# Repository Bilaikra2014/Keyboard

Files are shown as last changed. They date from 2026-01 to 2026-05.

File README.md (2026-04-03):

# ⌨️ WirelessKeyboard Project

Ce projet a pour objectif la conception et la fabrication d'un clavier mécanique (Filaire USB-C / Sans-fil). Le système repose sur un écosystème ESP32 permettant une communication rapide et personnalisée. Ce projet est une première version de test, une autre version pourrait être conçue dans le but de rechercher encore plus de perfomance en utilisant des composants plus adaptés.

## 📋 Présentation du projet

Le projet consiste à créer deux dispositifs distincts :
1.  **Le Clavier (Émetteur) :** Gère la matrice de touches, la batterie et la communication.
2.  **Le Récepteur (Dongle) :** Reçoit les données sans fil et les transmet à l'ordinateur via USB.

L'architecture se divise en trois axes de développement :
* **Électronique :** Conception des schémas et des PCB.
* **Informatique :** Développement des firmwares d'émission et de réception.
* **Mécanique :** Conception CAO 3D du boîtier du clavier et de celui dongle.

---

## 🛠️ Spécifications Matérielles

### 1. Le Clavier (ESP32-S3)
Le choix de l'**ESP32-S3** est motivé par son support **USB natif**, indispensable pour le mode filaire.
* **Prise USB C** pour le mode filaire.
* **Alimentation :** Batterie LiPo 1S (3.7V).
* **Régulation :** Passage du 5V(USB)/3v7(Batterie) vers 3.3V via un régulateur de tension (LDO).
* **Gestion de charge :** Circuit de charge intégré permettant :
    * L'alimentation du µC via USB lors du branchement.
    * La recharge simultanée de la batterie.
    * Le basculement automatique sur batterie lors du débranchement.

### 2. Le Récepteur (ESP32-S3-MINI)

      

L'**ESP32-S3-MINI** est utilisé pour son format compact et son coût réduit. Il fait office de pont entre le clavier et le PC.
* **Prise USB A** pour le brancher à l'ordinateur.
* **Interface :** Prise USB-A mâle.
* **Alimentation :** LDO convertissant le 5V USB en 3.3V.
* **Contrôles physiques :**
    * **Bouton BOOT :** Maintien du GPIO 9 à la masse pour le mode téléchargement.
    * **Bouton RESET :** Redémarrage du contrôleur pour les phases de test.
* **Câblage USB natif :**
    * `D+` ↔ GPIO 19
    * `D-` ↔ GPIO 18
    * `V+` ↔ Entrée LDO
    * `GND` ↔ Masse commune

---

## 📂 Structure du projet

Chaque sous-structure du projet aura son propre fichier Readme dédiée à la partie qu'elle traite.

```text
.
├── 📁 Electronique        # Schémas et PCB (KiCad)
│   ├── 📁 Lib              # Librairie Kicad
│   ├── 📁 Clavier          # Code de l'émetteur
│   └── 📁 Recepteur        # Code du récepteur
├── 📁 Informatique        # Code source ESP32
│   ├── 📁 Clavier          # Code de l'émetteur
│   └── 📁 Recepteur        # Code du récepteur
├── 📁 Mecanique          # Modèles 3D (STL/STEP)
└── README.md                #README global du projet

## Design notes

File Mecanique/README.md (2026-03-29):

La partie mécanique se divise en 3 principales étapes : 
- La plaque de maintient (Switch Plate) qui permettra d'aligner parfaitement les switchs lors de la soudure.
- Les touches de clavier (KeyCaps) pour appuyer sur les switchs
- Le boitier du clavier.

plaque : https://www.keyboard-layout-editor.com/#/gists/d94be4b51da24dfe0b23f572a5654290
touches : https://srwi.github.io/keycap_generator/

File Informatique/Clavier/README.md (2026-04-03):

# Partie informatique - Clavier

## Fonctions à réaliser

- Lire les touches de la matrice
- Lire l'encodeurs
- Détecter le mode d'alimentation : 
  - Alimentation sur batterie : Clavier en mode sans-fil donc les touches sont envoyées par ESP-NOW
  - Alimentation par USB : Clavier en mode filaire
- Mesurer la charge de la batterie et gérer l'activation de la charge.

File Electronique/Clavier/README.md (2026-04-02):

# Partie Electronique - Clavier

Dans cette partie, le clavier se sépare en deux sous-ensembles : la matrice de touche ainsi que la carte avec l'ESP32. Ces deux touches seront reliées de manière filaire. 
Séparer ces 2 sous-ensembles a permit un routage plus simple niveau PCB.

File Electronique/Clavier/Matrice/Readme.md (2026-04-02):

 # Partie electronique - Matrice de touche et encodeur
 
## Matrice de touche

Le clavier comporte 71 touches. Avec un système de surveillance normal des touches, il faudrait 71 GPIOs ce qui est beaucoup trop. Un système de matrice à donc été utilisé, permettant ainsi de réduire le nombre de broches utilisées. La matrice de touche se compose de 5 lignes et 15 colonnes, ce qui fait que l'on utiliser que 20 GPIOs. 

**Fonctionnement de la matrice** : 
- Le µC met successivement chaque ligne à l'état BAS.
- Il lit ensuite l'état des colonnes maintenues à l'état HAUT par des résistances de pull-up.
- Si une colonne est detectée à l'état BAS, c'est que la touche correspondant au croisement est activée.

**Le problème du Ghosting** : 

Sur une matrice simple, presser trois touches simultanément (ex: A, Q et S) peut créer un chemin de retour parasite. Le courant "remonte" par une ligne adjacente, faisant croire au contrôleur qu'une quatrième touche fantôme (Ghost) est pressée.
Pour pallier ce problème, chaque interrupteur est couplé à une diode de signal 1N4148 : 
- Rôle : Elle force le courant à circuler dans un seul sens (Ligne → Colonne).
- Résultat : Cela permet le N-Key Rollover (NKRO), garantissant que chaque pression de touche est enregistrée indépendamment, quel que soit le nombre de touches pressées simultanément.

Les touches utilisées sont des switchs mécanique **Cherry MX Red** commandés sur AliExpress.



## Gestion de l'encodeur

L'encodeur permet la gestion du volume.

L'encodeur utilisé (déjà présent à l'école) possède une fonction RGB avec les 3 diodes (pin 1,2 et 4) mais ne seront pas utilisée ici.



## Résultat final

Voici la vue 3D du Résultat final via logiciel : 



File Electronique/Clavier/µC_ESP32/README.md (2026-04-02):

 # Partie electronique - Microcontrôleur
## Gestion d'alimentation et Chargeur Li-Po

Lorsque la batterie est déchargée, le clavier sera branché à l'ordinateur via une prise USB. La prise de l'ordinateur va alimenter le clavier, et charger la batterie avec le courant restant. Une prise USB A d'ordinateur peut fournir en général jusqu'à 500 mA. 

Pour gérer l'alimentation et la charge, le composant utilisé sera le [MCP73871](https://ww1.microchip.com/downloads/en/DeviceDoc/MCP73871-Data-Sheet-20002090E.pdf) qui permet : 
  - **Gestion du Power Path** : Alimente le système depuis l'USB tout en gérant la charge la batterie
  - **Partage du courant** : Donne la priorité à l'alimentation du système, le courant restant est alloué à la charge de la batterie



**Alimentation et Puissance**
  - In (18) : Alimentation du composant -> USB
  - Out (20) : Alimentation du système -> Régulateur LDO
  - Vbat (14) : Charge de la batterie -> Vbat
  - Vss (10) : Masse -> GND

**Contrôle et Logique**:
  - SEL (3) : Limite de courant à tirer sur l'USB -> LOW pour 500 mA (HIGH pour 1,8)
  - PROG2 (4) : Courant d'entré max à tirer -> HIGH pour 500 mA (HIGH pour 100mA)  
  - CE (17) : Activation du système à l'état haut -> Vusb
  - TE (9) : Sécurité interne du temps de charge -> GND

**Programmation et Sécurité**:
  - PROG1 (13) : Courant de charge rapide -> R = 1000V/Ireg, on veut Ireg = 250mA donc R = 4k
  - PROG3 (12) : Seuil de fin de charge -> R = 40k
  - VPCC (2)   : 
  - VBAT_S (16): Sonde de tension -> Vbat
  - THERM (5)  : Capteur de temperature ->  

**Indicateurs visuel**: Ces broches tirent vers la masse, on y connecte des leds
  - PG (6)    : Indication que l'USB est branché, à brancher à l'ESP32 pour qu'il detecte si on est sur batterie ou USB
  - STAT1 (8) : Indication de la phase de charge 
  - STAT2 (7) : Indication de la fin de charge 

## Régulateur de tension

Le µC sera alimenté par du 5v ou bien du 3v7, or il n'accepte que du 3v3. Il faut donc utiliser un régulateur de tension. Le régulateur de tension utilisé est un [BU33SD5WGTR](https://www.rohm.com/products/power-management/linear-regulators/single-output-ldo-regulators/bu33sd5wg-product).



## Mesure de la batterie

La mesure de la batterie permet d'indiquer à l'utilisateur si le clavier à besoin d'être chargé ou pas. La tension étant supérieur aux 3v3 de l'esp32, il faut diviser cette tension pour qu'elle puisse être lue par l'esp32 à travers un pont diviseur de tension.



**Pont Diviseur de tension**:

Le pont diviseur de tension formé par R16 et R17 permet d'ajuster la tension mesurée par L'ESP32. La tension de la batterie varie entre 4v2 et 3v7, ce qui donnera pour l'ESP32 une tension mesurée entre 3v et 2,64v, ce qui est dans la plage de donnée mesurable.

**Ajout des transistors Q3 et Q4**:

Utiliser simplement un pont diviseur consommerait du courant en permanance, aussi minime soit-il. C'est pour cela que des transistors ont été ajouté. Le transistor Q2 est un mosfet canal P, qui lie la batterie au pont diviseur lorsqu'il est passant. Ce transistor est piloté par son complémentaire Q1, un canal N commandé par l'esp32. Ce transistor sera passant uniquement lors de la mesure déclenchée par l'ESP32. La résistance R15 sert de pull-up pour maintenir le transistor Q2 bloqué quand Q1 est bloqué. Ce montage permet de relier le pont diviseur à la batterie uniquement lors de la mesure, limitant ainsi la consommation du pont diviseur.

## USB-C et protection ESD

Le port USB-C permet l'utilisation filaire du clavier, ainsi que la recharge de la batterie.



Les broches D+ et D- permettent la communication ESP32-Ordinateur. 
Les broches CC1 et CC2 doivent être liées à des résistances de 5k1 de pull-down pour que la source détecte la présence du clavier et délivre ainsi le 5v.

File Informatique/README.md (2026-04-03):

## 📡 Protocoles de Communication

### Communication Sans-fil ([ESP-NOW](https://wiki-fablab.grandbesancon.fr/doku.php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,de%20donn%C3%A9es%20directement%20et%20simplement.))
Pour minimiser la latence, le projet utilise **ESP-NOW**, un protocole de connexion sans fil à basse consommation d'Espressif annoncé avec une latence < 10ms.

### Communication PC
Le récepteur utilise les bibliothèques `USB.h` et `USBHIDKeyboard.h` pour simuler un clavier standard auprès du système d'exploitation.

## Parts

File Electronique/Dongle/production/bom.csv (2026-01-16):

Designator | Footprint | Quantity | Value | LCSC Part #
C1, C2 | 0603 | 2 | 1µ
D4, D5 | 0603 | 2 | LED
J1 | USB_A_CNCTech_1001-011-01101_Horizontal | 1 | USB_A
R2, R3 | 0805 | 2 | 470
R4, R5 | 0805 | 2 | 10k
SW3, SW4 | SW_Tactile_SPST_NO_Straight_CK_PTS636Sx25SMTRLFS | 2 | SW_Push
U3 | ESP32-S2-MINI-1 | 1 | ESP32-S3-MINI-1
U4 | SOT-23-5 | 1 | TLV75533PDBV

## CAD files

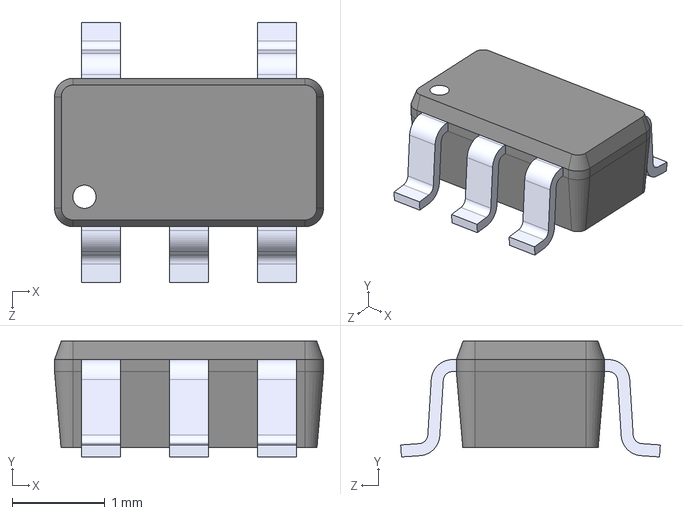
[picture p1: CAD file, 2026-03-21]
Electronique/Clavier/Matrice/Librairie/3D_model/BU33SD5WG-TR.step
2.90 x 1.25 x 2.80 mm

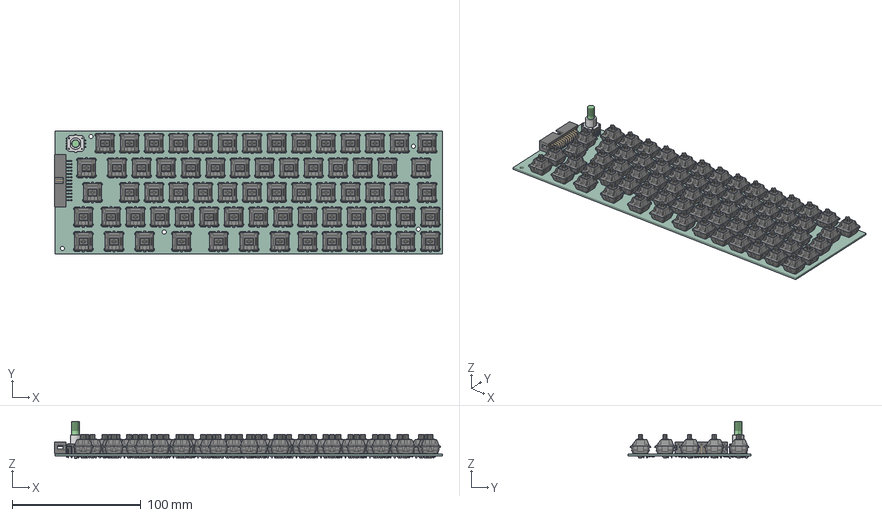
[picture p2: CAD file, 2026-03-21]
Electronique/Clavier/Matrice/matrice.step
300.9 x 95.6 x 29.0 mm
MX1A11NN--3DModel-STEP-510211 x 70
COM-15141
IDC-Header_2x13_P2.54mm_Horizontal
D_SOD-523 x 70
R_0805_2012Metric x 3
matrice_PCB

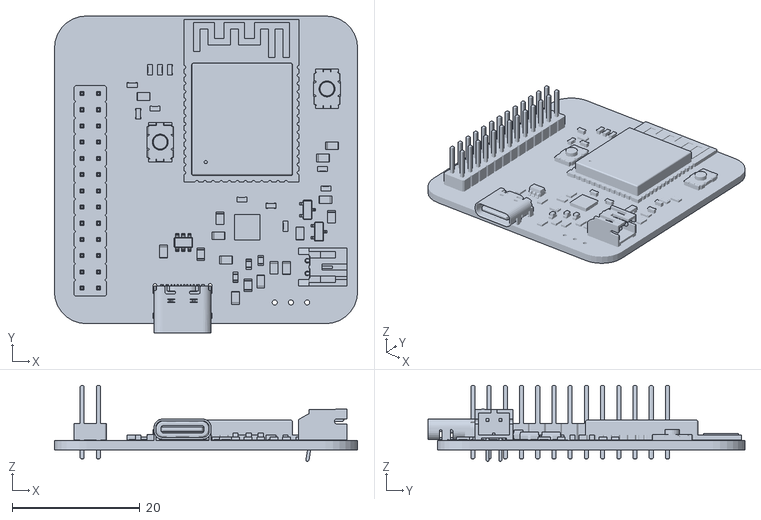
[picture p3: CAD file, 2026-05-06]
Electronique/Clavier/µC_ESP32/.stl
47.5 x 49.7 x 11.9

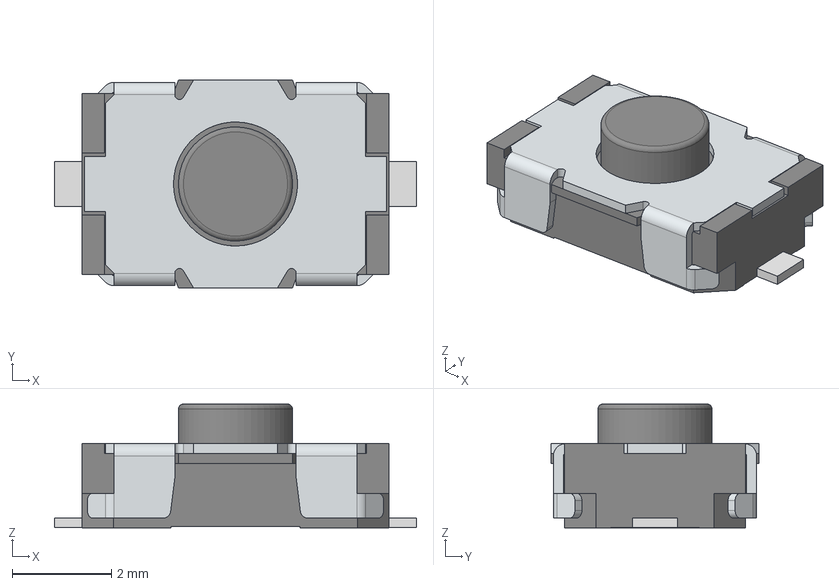
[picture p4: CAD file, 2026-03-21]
Electronique/Clavier/µC_ESP32/Librairie/3D_model/PushButton.step
7.30 x 4.20 x 2.50 mm
Base_oa_0
Cover
Pins

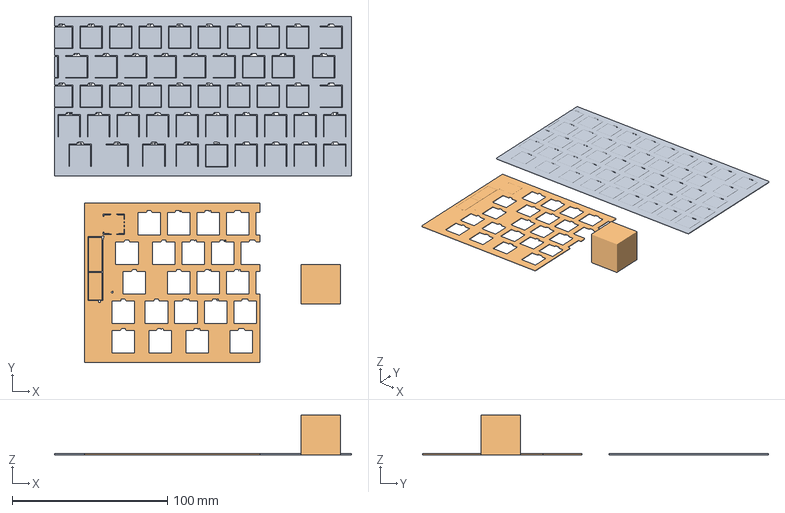
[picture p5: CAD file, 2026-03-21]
Mecanique/tinker.3mf
191.7 x 223.2 x 25.6 mm
tinker.obj_A
tinker.obj_B

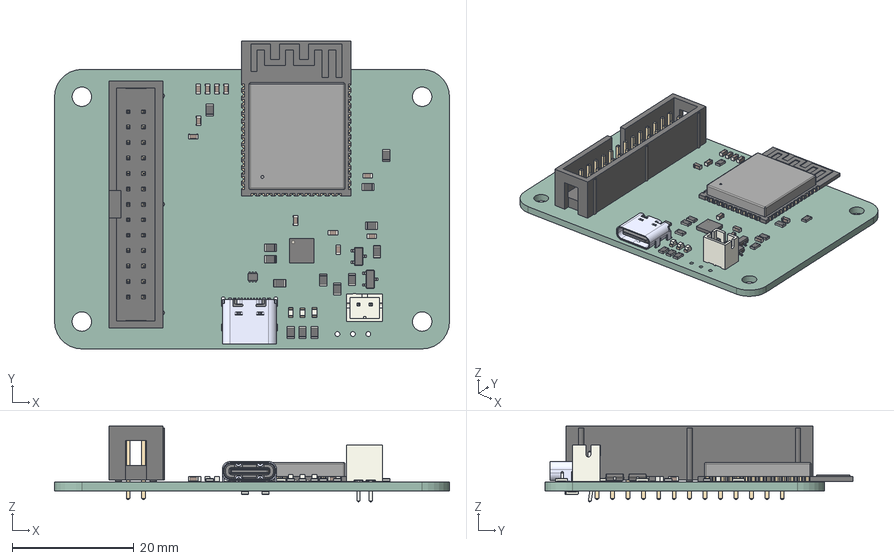
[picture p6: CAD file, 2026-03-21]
Electronique/Clavier/µC_ESP32/clavier.step
65.0 x 50.7 x 12.5 mm
C_0603_1608Metric x 11
JST_PH_B2B-PH-K_1x02_P2.00mm_Vertical
R_0805_2012Metric x 16
USBC
LED_0603_1608Metric x 3
ESP32-S3-WROOM-1
SOT-666
IDC-Header_2x13_P2.54mm_Vertical
QFN-20-1EP_4x4mm_P0.5mm_EP2.5x2.5mm
SOT-23 x 2
clavier_PCB

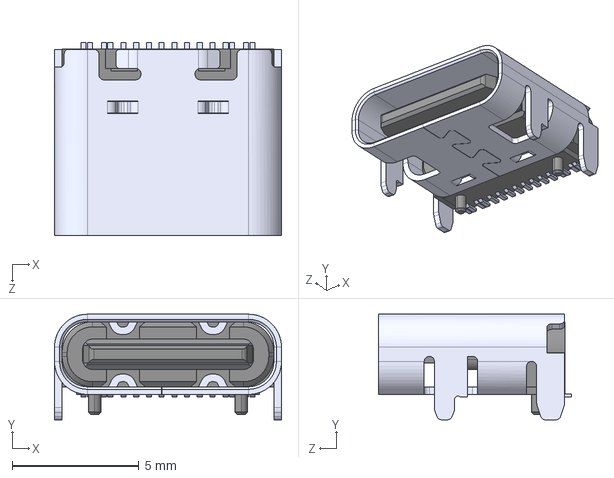
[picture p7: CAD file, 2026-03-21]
Electronique/Clavier/Matrice/Librairie/3D_model/USBC.STEP
8.94 x 4.16 x 7.60 mm

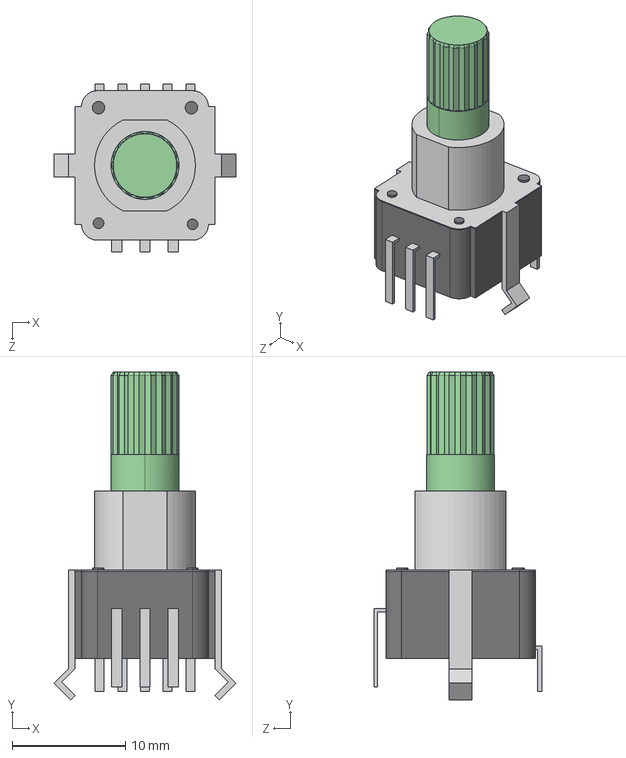
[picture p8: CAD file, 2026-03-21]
Electronique/Clavier/µC_ESP32/Librairie/3D_model/COM-15141.stp
16.0 x 29.0 x 14.8 mm

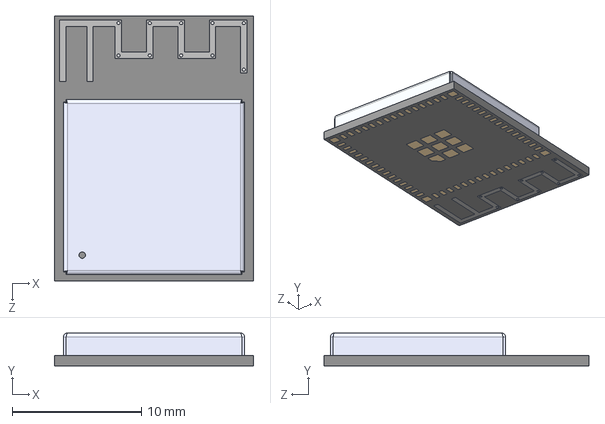
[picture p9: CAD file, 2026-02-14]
Electronique/Clavier/Matrice/Librairie/3D_model/ESP32-S3-MINI-1-N8.step
15.4 x 2.55 x 20.5 mm

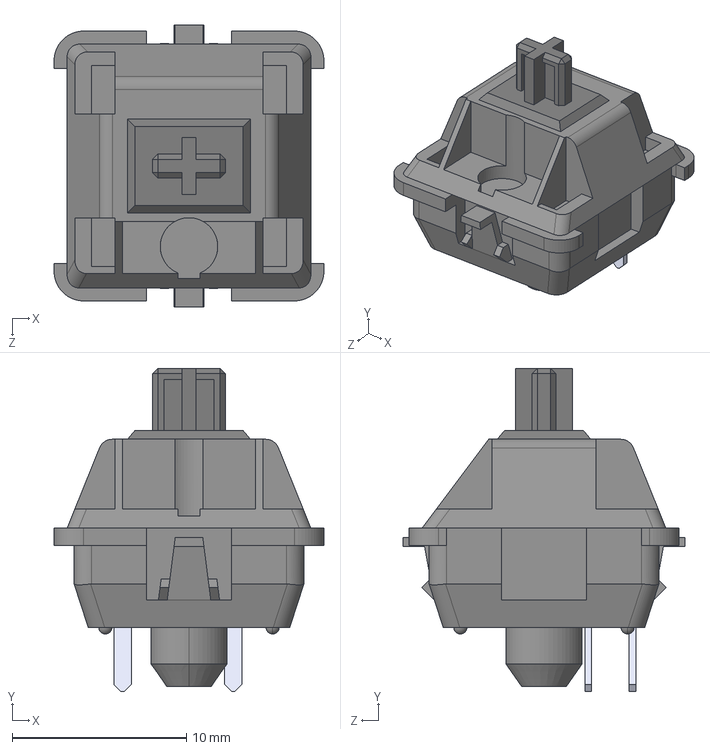
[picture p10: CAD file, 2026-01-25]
Electronique/Clavier/Matrice/Librairie/3D_model/MX1A11NN--3DModel-STEP-510211.STEP
15.5 x 18.5 x 16.2 mm

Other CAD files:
Electronique/Clavier/µC_ESP32/clavier.stl

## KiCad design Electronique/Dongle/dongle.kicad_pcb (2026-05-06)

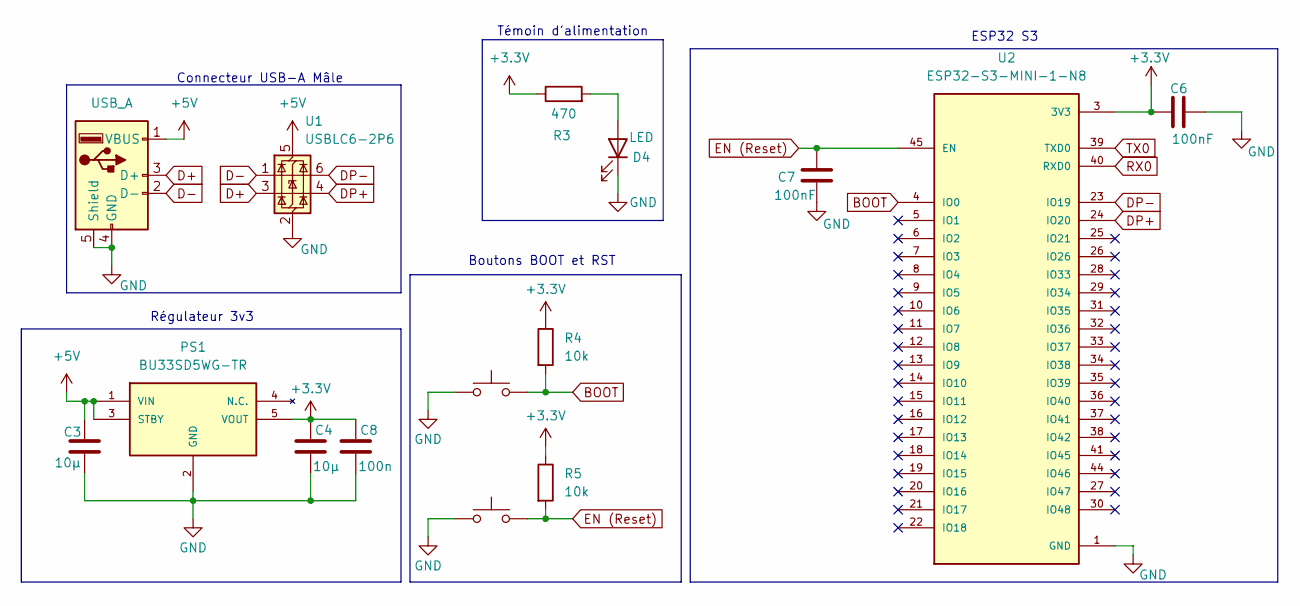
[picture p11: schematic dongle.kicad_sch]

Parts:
C3, C4: 10µ; C_0603_1608Metric_Pad1.08x0.95mm_HandSolder
C6, C7: 100nF; C_0603_1608Metric_Pad1.08x0.95mm_HandSolder
C8: 100n; C_0603_1608Metric_Pad1.08x0.95mm_HandSolder
D4: LED; LED_0603_1608Metric
J1: USB_A; USB_A_CNCTech_1001-011-01101_Horizontal
PS1: BU33SD5WG-TR; SOT95P280X125-5N; MOUSER_PART_NUMBER 755-BU33SD5WG-TR
R3: 470; R_0805_2012Metric
R4, R5: 10k; R_0805_2012Metric
SW3: BOOT; 434771025826
SW4: RST; 434771025826
U1: USBLC6-2P6; SOT-23-6
U2: ESP32-S3-MINI-1-N8; PARTREV v0.6

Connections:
+3.3V: C4.1, C6.2, C8.1, PS1.5 (VOUT), R3.1, R4.1, R5.1, U2.3 (3V3)
+5V: C3.1, J1.1 (VBUS), PS1.1 (VIN), PS1.3 (STBY), U1.5 (VBUS)
BOOT: R4.2, SW3.2, U2.4 (IO0)
D+: J1.3 (D+), U1.3 (I/O2)
D-: J1.2 (D-), U1.1 (I/O1)
DP+: U1.4 (I/O2), U2.24 (IO20)
DP-: U1.6 (I/O1), U2.23 (IO19)
EN (Reset): C7.1, R5.2, SW4.2, U2.45 (EN)
GND: C3.2, C4.2, C6.1, C7.2, C8.2, D4.1 (K), J1.4 (GND), J1.5 (Shield), PS1.2 (GND), SW3.1, SW4.1, U1.2 (GND), U2.1 (GND), U2.2 (GND), U2.42 (GND), U2.43 (GND), U2.46 (GND), U2.47 (GND), U2.48 (GND), U2.49 (GND), U2.50 (GND), U2.51 (GND), U2.52 (GND), U2.53 (GND), U2.54 (GND), U2.55 (GND), U2.56 (GND), U2.57 (GND), U2.58 (GND), U2.59 (GND), U2.60 (GND), U2.61 (GND), U2.61_1 (GND), U2.61_2 (GND), U2.61_3 (GND), U2.61_4 (GND), U2.61_5 (GND), U2.61_6 (GND), U2.61_7 (GND), U2.61_8 (GND), U2.62 (GND), U2.63 (GND), U2.64 (GND), U2.65 (GND)
unnamed: D4.2 (A), R3.2
RX0: U2.40 (RXD0)
TX0: U2.39 (TXD0)

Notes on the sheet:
Témoin d'alimentation
Connecteur USB-A Mâle
Boutons BOOT et RST
ESP32 S3
Régulateur 3v3

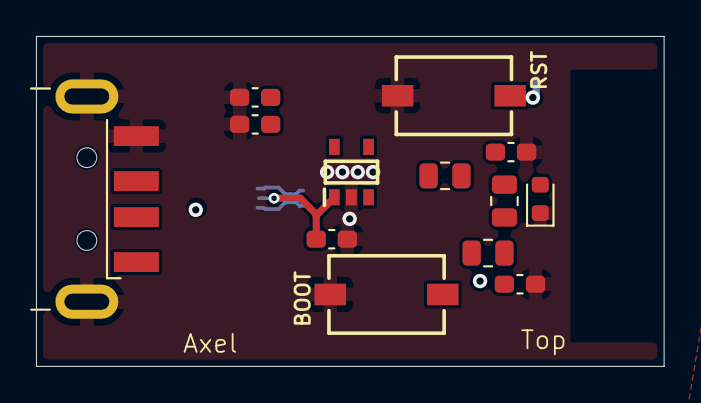
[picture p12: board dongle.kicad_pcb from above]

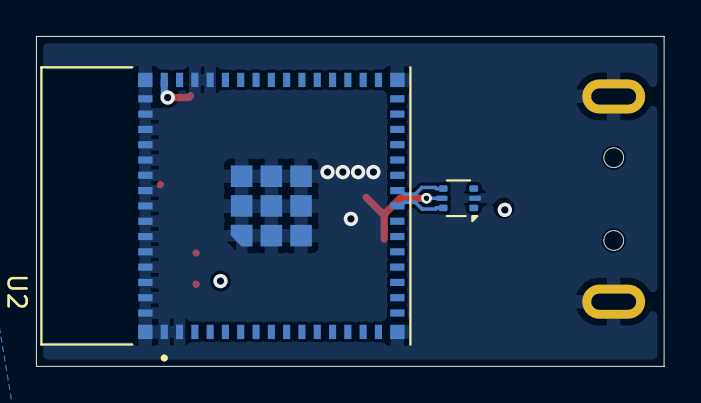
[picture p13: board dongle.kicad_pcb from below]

Board: 2 copper layers, 34.9 x 18.3 mm, 15 parts (2 on the bottom side), 10 nets.

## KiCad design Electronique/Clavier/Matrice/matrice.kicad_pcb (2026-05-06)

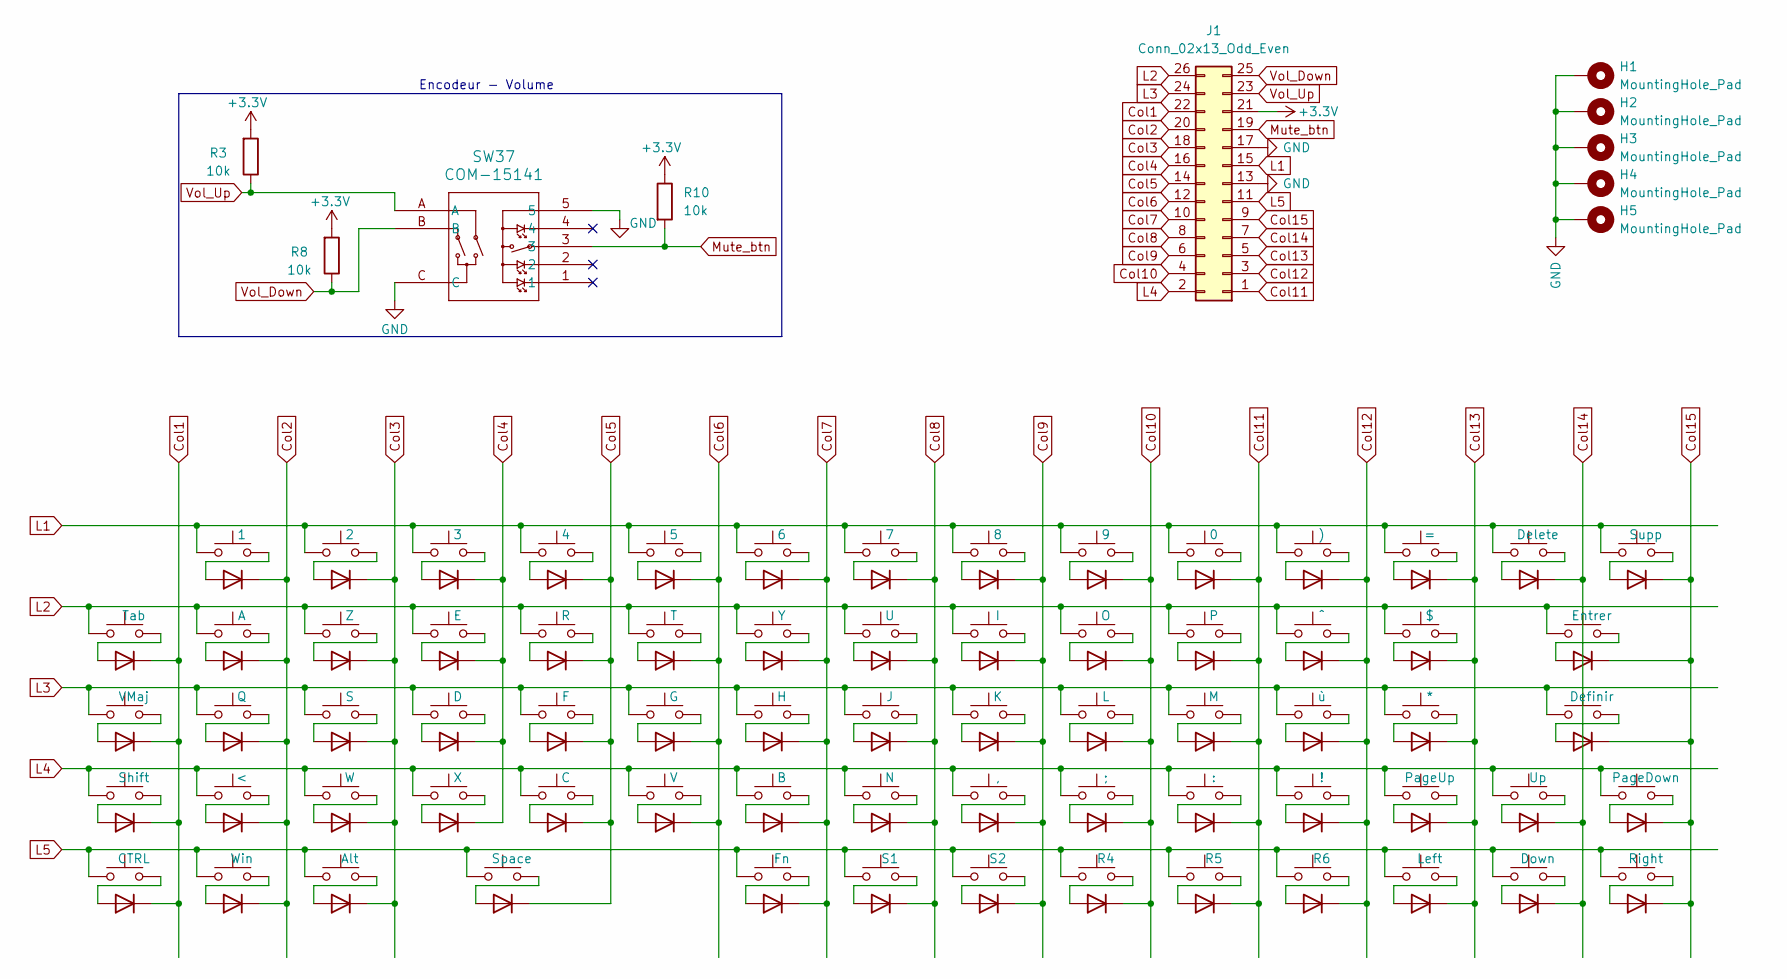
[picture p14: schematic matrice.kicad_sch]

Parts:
D2, D3, D4, D5, D6, D7, D8, D9, D10, D11, D12, D13, D14, D15, D16, D17, D18, D19, D20, D21, D22, D23, D24, D25, D26, D27, D28, D29, D30, D31, D32, D33, D34, D35, D36, D37, D38, D39, D40, D41, D42, D43, D44, D45, D46, D47, D48, D49, D50, D51, D52, D53, D54, D55, D56, D57, D58, D59, D60, D61, D62, D63, D64, D65, D66, D67, D69, D70, D71, D72: 1N4148WT; D_SOD-523
H1, H2, H3, H4, H5: MountingHole_Pad; MountingHole_3.2mm_M3_DIN965_Pad
J1: Conn_02x13_Odd_Even; IDC-Header_2x13_P2.54mm_Horizontal
R3, R8, R10: 10k; R_0805_2012Metric
SW2: Tab; SW_Cherry_MX_Plate_1.50u
SW3: VMaj; SW_Cherry_MX_Plate_2.00u
SW4: Shift; SW_Cherry_MX_Plate_1.25u
SW5: CTRL; SW_Cherry_MX_Plate_1.25u
SW6: 1; SW_Cherry_MX_Plate_1.00u
SW7: A; SW_Cherry_MX_Plate_1.00u
SW8: Q; SW_Cherry_MX_Plate_1.00u
SW9: <; SW_Cherry_MX_Plate_1.00u
SW10: Win; SW_Cherry_MX_Plate_1.25u
SW11: 2; SW_Cherry_MX_Plate_1.00u
SW12: Z; SW_Cherry_MX_Plate_1.00u
SW13: S; SW_Cherry_MX_Plate_1.00u
SW14: W; SW_Cherry_MX_Plate_1.00u
SW15: Alt; SW_Cherry_MX_Plate_1.25u
SW16: 3; SW_Cherry_MX_Plate_1.00u
SW17: E; SW_Cherry_MX_Plate_1.00u
SW18: D; SW_Cherry_MX_Plate_1.00u
SW19: X; SW_Cherry_MX_Plate_1.00u
SW20: 4; SW_Cherry_MX_Plate_1.00u
SW21: R; SW_Cherry_MX_Plate_1.00u
SW22: F; SW_Cherry_MX_Plate_1.00u
SW23: C; SW_Cherry_MX_Plate_1.00u
SW24: 5; SW_Cherry_MX_Plate_1.00u
SW25: T; SW_Cherry_MX_Plate_1.00u
SW26: G; SW_Cherry_MX_Plate_1.00u
SW27: V; SW_Cherry_MX_Plate_1.00u
SW28: Space; SW_Cherry_MX_Plate_1.75u
SW29: 6; SW_Cherry_MX_Plate_1.00u
SW30: Y; SW_Cherry_MX_Plate_1.00u
SW31: H; SW_Cherry_MX_Plate_1.00u
SW32: B; SW_Cherry_MX_Plate_1.00u
SW33: 7; SW_Cherry_MX_Plate_1.00u
SW34: U; SW_Cherry_MX_Plate_1.00u
SW35: J; SW_Cherry_MX_Plate_1.00u
SW36: N; SW_Cherry_MX_Plate_1.00u
SW37: COM-15141; COM-15141_SPK
SW38: 8; SW_Cherry_MX_Plate_1.00u
SW39: I; SW_Cherry_MX_Plate_1.00u
SW40: K; SW_Cherry_MX_Plate_1.00u
SW41: ,; SW_Cherry_MX_Plate_1.00u
SW42: 9; SW_Cherry_MX_Plate_1.00u
SW43: O; SW_Cherry_MX_Plate_1.00u
SW44: L; SW_Cherry_MX_Plate_1.00u
SW45: ;; SW_Cherry_MX_Plate_1.00u
SW46: 0; SW_Cherry_MX_Plate_1.00u
SW47: P; SW_Cherry_MX_Plate_1.00u
SW48: M; SW_Cherry_MX_Plate_1.00u
SW49: :; SW_Cherry_MX_Plate_1.00u
SW50: R5; SW_Cherry_MX_Plate_1.00u
SW51: ); SW_Cherry_MX_Plate_1.00u
SW52: ^; SW_Cherry_MX_Plate_1.00u
SW53: ù; SW_Cherry_MX_Plate_1.00u
SW54: !; SW_Cherry_MX_Plate_1.00u
SW55: R6; SW_Cherry_MX_Plate_1.00u
SW56: =; SW_Cherry_MX_Plate_1.00u
SW57: $; SW_Cherry_MX_Plate_1.00u
SW58: *; SW_Cherry_MX_Plate_1.00u
SW59: PageUp; SW_Cherry_MX_Plate_1.00u
SW60: Left; SW_Cherry_MX_Plate_1.00u
SW61: Delete; SW_Cherry_MX_Plate_1.00u
SW62: Up; SW_Cherry_MX_Plate_1.00u
SW63: Down; SW_Cherry_MX_Plate_1.00u
SW64: Entrer; SW_Cherry_MX_Plate_1.75u
SW65: Definir; SW_Cherry_MX_Plate_1.25u
SW66: Supp; SW_Cherry_MX_Plate_1.25u
SW67: PageDown; SW_Cherry_MX_Plate_1.00u
SW68: Right; SW_Cherry_MX_Plate_1.00u
SW70: Fn; SW_Cherry_MX_Plate_1.25u
SW71: S1; SW_Cherry_MX_Plate_1.25u
SW72: S2; SW_Cherry_MX_Plate_1.25u
SW73: R4; SW_Cherry_MX_Plate_1.00u

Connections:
+3.3V: J1.21, R3.2, R8.2, R10.1
Col1: D2.1 (K), D3.1 (K), D4.1 (K), D5.1 (K), J1.22
Col2: D6.1 (K), D7.1 (K), D8.1 (K), D9.1 (K), D10.1 (K), J1.20
Col3: D11.1 (K), D12.1 (K), D13.1 (K), D14.1 (K), D15.1 (K), J1.18
Col4: D16.1 (K), D17.1 (K), D18.1 (K), D19.1 (K), J1.16
Col5: D20.1 (K), D21.1 (K), D22.1 (K), D23.1 (K), D28.1 (K), J1.14
Col6: D24.1 (K), D25.1 (K), D26.1 (K), D27.1 (K), J1.12
Col7: D29.1 (K), D30.1 (K), D31.1 (K), D32.1 (K), D69.1 (K), J1.10
Col8: D33.1 (K), D34.1 (K), D35.1 (K), D36.1 (K), D70.1 (K), J1.8
Col9: D37.1 (K), D38.1 (K), D39.1 (K), D40.1 (K), D71.1 (K), J1.6
Col10: D41.1 (K), D42.1 (K), D43.1 (K), D44.1 (K), D72.1 (K), J1.4
Col11: D45.1 (K), D46.1 (K), D47.1 (K), D48.1 (K), D49.1 (K), J1.1
Col12: D50.1 (K), D51.1 (K), D52.1 (K), D53.1 (K), D54.1 (K), J1.3
Col13: D55.1 (K), D56.1 (K), D57.1 (K), D58.1 (K), D59.1 (K), J1.5
Col14: D60.1 (K), D61.1 (K), D62.1 (K), J1.7
Col15: D63.1 (K), D64.1 (K), D65.1 (K), D66.1 (K), D67.1 (K), J1.9
GND: H1.1 (1_1), H2.1 (1_1), H3.1 (1_1), H4.1 (1_1), H5.1 (1_1), J1.13, J1.17, SW37.5, SW37.C
L1: J1.15, SW6.1, SW11.1, SW16.1, SW20.1, SW24.1, SW29.1, SW33.1, SW38.1, SW42.1, SW46.1, SW51.1, SW56.1, SW61.1, SW66.1
L2: J1.26, SW2.1, SW7.1, SW12.1, SW17.1, SW21.1, SW25.1, SW30.1, SW34.1, SW39.1, SW43.1, SW47.1, SW52.1, SW57.1, SW64.1
L3: J1.24, SW3.1, SW8.1, SW13.1, SW18.1, SW22.1, SW26.1, SW31.1, SW35.1, SW40.1, SW44.1, SW48.1, SW53.1, SW58.1, SW65.1
L4: J1.2, SW4.1, SW9.1, SW14.1, SW19.1, SW23.1, SW27.1, SW32.1, SW36.1, SW41.1, SW45.1, SW49.1, SW54.1, SW59.1, SW62.1, SW67.1
L5: J1.11, SW5.1, SW10.1, SW15.1, SW28.1, SW50.1, SW55.1, SW60.1, SW63.1, SW68.1, SW70.1, SW71.1, SW72.1, SW73.1
Mute_btn: J1.19, R10.2, SW37.3
unnamed: D2.2 (A), SW2.2
unnamed: D3.2 (A), SW3.2
unnamed: D4.2 (A), SW4.2
unnamed: D5.2 (A), SW5.2
unnamed: D6.2 (A), SW6.2
unnamed: D7.2 (A), SW7.2
unnamed: D8.2 (A), SW8.2
unnamed: D9.2 (A), SW9.2
unnamed: D10.2 (A), SW10.2
unnamed: D11.2 (A), SW11.2
unnamed: D12.2 (A), SW12.2
unnamed: D13.2 (A), SW13.2
unnamed: D14.2 (A), SW14.2
unnamed: D15.2 (A), SW15.2
unnamed: D16.2 (A), SW16.2
unnamed: D17.2 (A), SW17.2
unnamed: D18.2 (A), SW18.2
unnamed: D19.2 (A), SW19.2
unnamed: D20.2 (A), SW20.2
unnamed: D21.2 (A), SW21.2
unnamed: D22.2 (A), SW22.2
unnamed: D23.2 (A), SW23.2
unnamed: D24.2 (A), SW24.2
unnamed: D25.2 (A), SW25.2
unnamed: D26.2 (A), SW26.2
unnamed: D27.2 (A), SW27.2
unnamed: D28.2 (A), SW28.2
unnamed: D29.2 (A), SW29.2
unnamed: D30.2 (A), SW30.2
unnamed: D31.2 (A), SW31.2
unnamed: D32.2 (A), SW32.2
unnamed: D33.2 (A), SW33.2
unnamed: D34.2 (A), SW34.2
unnamed: D35.2 (A), SW35.2
unnamed: D36.2 (A), SW36.2
unnamed: D37.2 (A), SW38.2
unnamed: D38.2 (A), SW39.2
unnamed: D39.2 (A), SW40.2
unnamed: D40.2 (A), SW41.2
unnamed: D41.2 (A), SW42.2
unnamed: D42.2 (A), SW43.2
unnamed: D43.2 (A), SW44.2
unnamed: D44.2 (A), SW45.2
unnamed: D45.2 (A), SW46.2
unnamed: D46.2 (A), SW47.2
unnamed: D47.2 (A), SW48.2
unnamed: D48.2 (A), SW49.2
unnamed: D49.2 (A), SW50.2
unnamed: D50.2 (A), SW51.2
unnamed: D51.2 (A), SW52.2
unnamed: D52.2 (A), SW53.2
unnamed: D53.2 (A), SW54.2
unnamed: D54.2 (A), SW55.2
unnamed: D55.2 (A), SW56.2
unnamed: D56.2 (A), SW57.2
unnamed: D57.2 (A), SW58.2
unnamed: D58.2 (A), SW59.2
unnamed: D59.2 (A), SW60.2
unnamed: D60.2 (A), SW61.2
unnamed: D61.2 (A), SW62.2
unnamed: D62.2 (A), SW63.2
unnamed: D63.2 (A), SW64.2
unnamed: D64.2 (A), SW65.2
unnamed: D65.2 (A), SW66.2
unnamed: D66.2 (A), SW67.2
unnamed: D67.2 (A), SW68.2
unnamed: D69.2 (A), SW70.2
unnamed: D70.2 (A), SW71.2
unnamed: D71.2 (A), SW72.2
unnamed: D72.2 (A), SW73.2
Vol_Down: J1.25, R8.1, SW37.B
Vol_Up: J1.23, R3.1, SW37.A

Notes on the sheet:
Encodeur - Volume

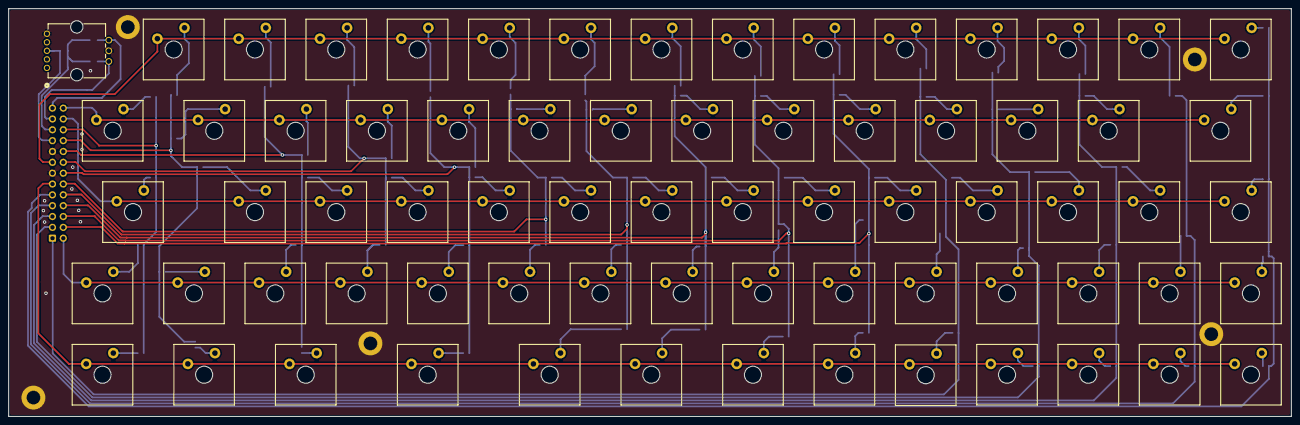
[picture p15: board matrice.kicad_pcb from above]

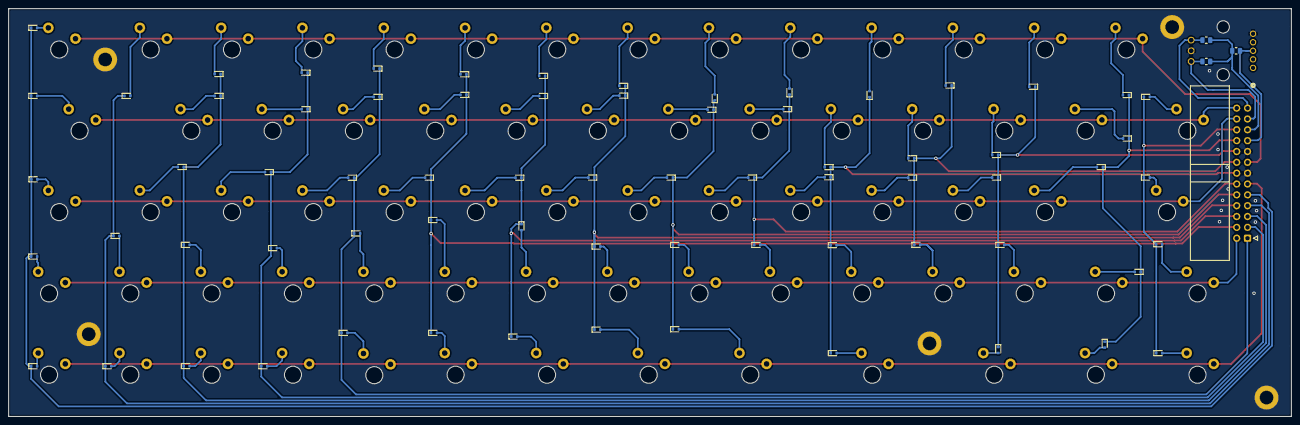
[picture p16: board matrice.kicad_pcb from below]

Board: 2 copper layers, 300.5 x 95.5 mm, 150 parts (74 on the bottom side), 95 nets.

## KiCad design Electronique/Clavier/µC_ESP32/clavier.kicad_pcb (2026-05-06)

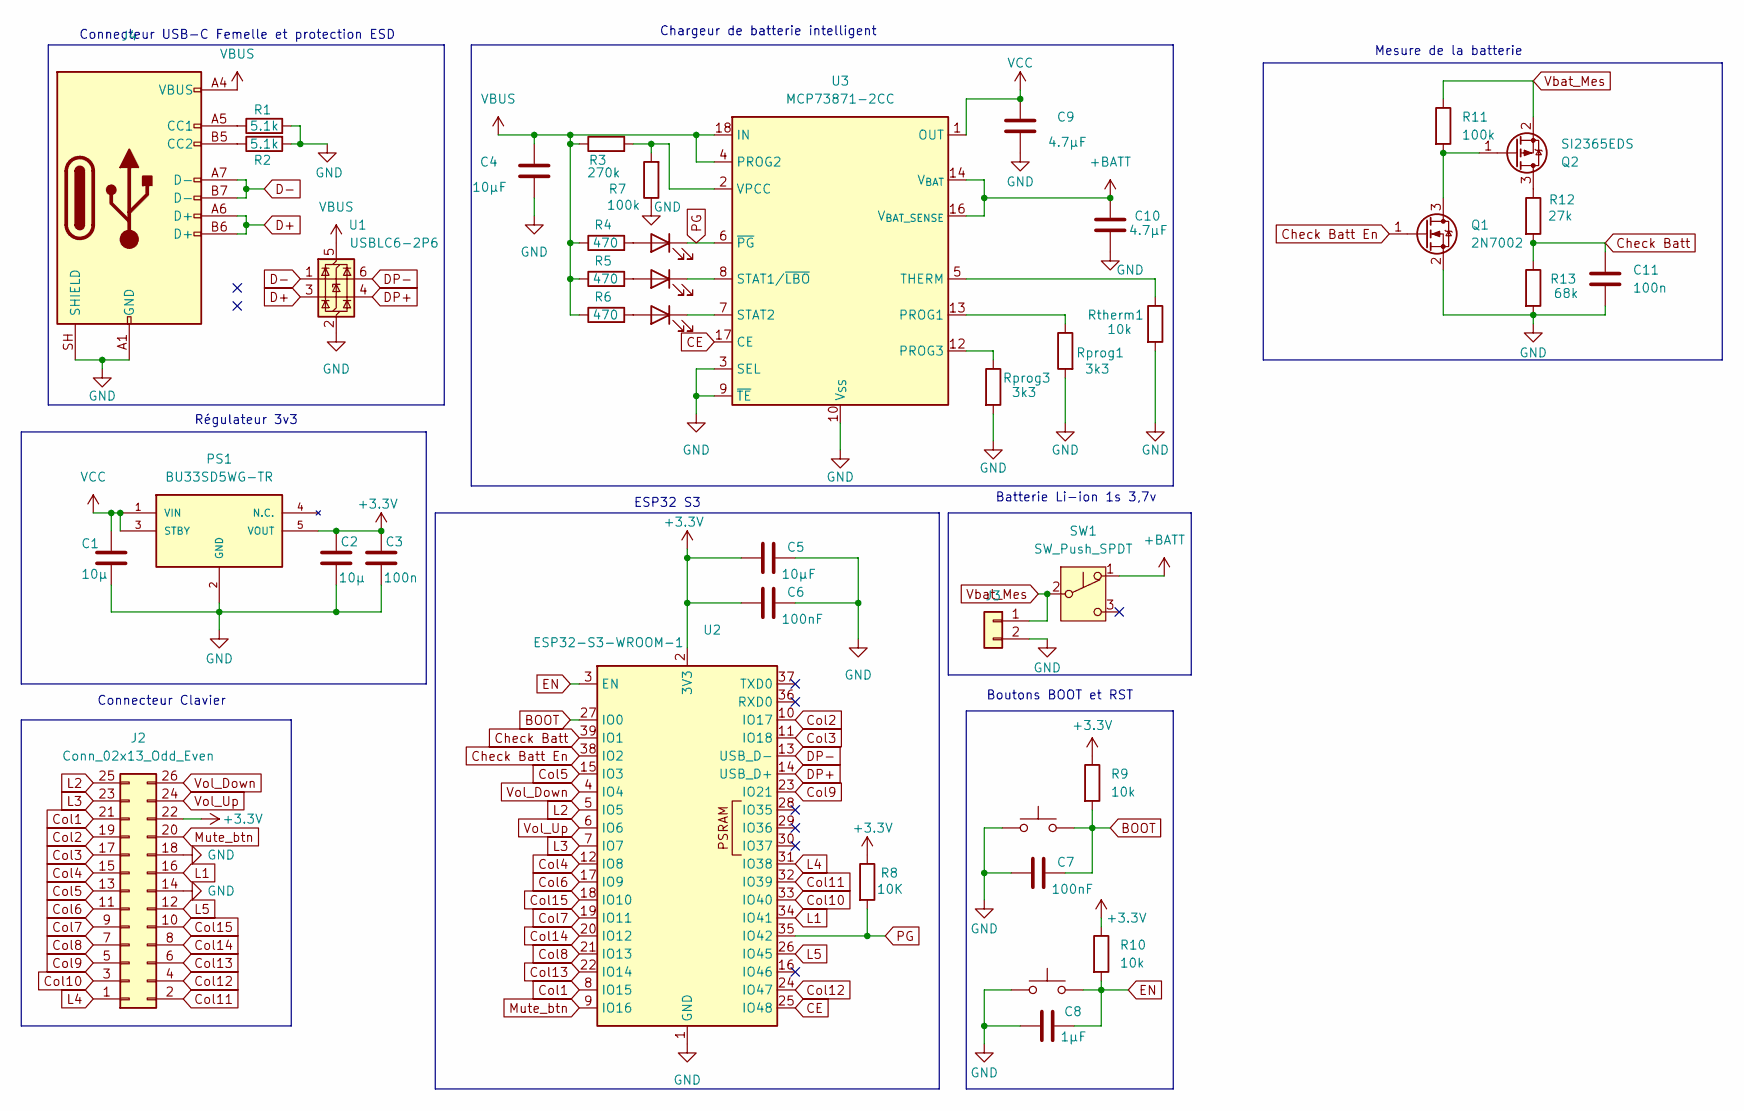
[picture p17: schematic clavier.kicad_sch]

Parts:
BOOT1: SW_Push; 434771025826
C1, C2: 10µ; C_0603_1608Metric_Pad1.08x0.95mm_HandSolder
C3, C11: 100n; C_0603_1608Metric_Pad1.08x0.95mm_HandSolder
C4, C5: 10µF; C_0603_1608Metric_Pad1.08x0.95mm_HandSolder
C6, C7: 100nF; C_0603_1608Metric_Pad1.08x0.95mm_HandSolder
C8: 1µF; C_0603_1608Metric_Pad1.08x0.95mm_HandSolder
C9, C10: 4.7µF; C_0603_1608Metric_Pad1.08x0.95mm_HandSolder
J2: Conn_02x13_Odd_Even; PinHeader_2x13_P2.54mm_Vertical
J3: JST_PH_S2B-PH-K_1x02_P2.00mm_Horizontal
J4: USB_C_Receptacle_USB2.0_14P; USB_C_Receptacle_XKB_U262-16XN-4BVC11
PG1: LED; LED_0603_1608Metric
PS1: BU33SD5WG-TR; SOT95P280X125-5N; MOUSER_PART_NUMBER 755-BU33SD5WG-TR
Q1: 2N7002; SOT-23
Q2: SI2365EDS; SOT-23
R1, R2: 5.1k; R_0805_2012Metric
R3: 270k; R_0805_2012Metric
R4, R5, R6: 470; R_0805_2012Metric
R7, R11: 100k; R_0805_2012Metric
R8: 10K; R_0805_2012Metric
R9, R10: 10k; R_0805_2012Metric
R12: 27k; R_0805_2012Metric
R13: 68k; R_0805_2012Metric
RST1: SW_Push; 434771025826
Rprog1, Rprog3: 3k3; R_0805_2012Metric
Rtherm1: 10k; R_0805_2012Metric
STAT1, STAT2: LED; LED_0603_1608Metric
SW1: SW_Push_SPDT; SW_Slide-03_Wuerth-WS-SLTV_10x2.5x6.4_P2.54mm
U1: USBLC6-2P6; SOT-23-6
U2: ESP32-S3-WROOM-1
U3: MCP73871-2CC; QFN-20-1EP_4x4mm_P0.5mm_EP2.5x2.5mm

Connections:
+3.3V: C2.1, C3.1, C5.2, C6.2, J2.22, PS1.5 (VOUT), R8.1, R9.1, R10.1, U2.2 (3V3)
+BATT: C10.1, SW1.1 (A), U3.14 (V_{BAT}), U3.15 (V_{BAT}), U3.16 (V_{BAT_SENSE})
BOOT: BOOT1.2, C7.1, R9.2, U2.27 (IO0)
CE: U2.25 (IO48), U3.17 (CE)
Check Batt: C11.2, R12.2, R13.1, U2.39 (IO1)
Check Batt En: Q1.1 (G), U2.38 (IO2)
Col1: J2.21, U2.8 (IO15)
Col2: J2.19, U2.10 (IO17)
Col3: J2.17, U2.11 (IO18)
Col4: J2.15, U2.12 (IO8)
Col5: J2.13, U2.15 (IO3)
Col6: J2.11, U2.17 (IO9)
Col7: J2.9, U2.19 (IO11)
Col8: J2.7, U2.21 (IO13)
Col9: J2.5, U2.23 (IO21)
Col10: J2.3, U2.33 (IO40)
Col11: J2.2, U2.32 (IO39)
Col12: J2.4, U2.24 (IO47)
Col13: J2.6, U2.22 (IO14)
Col14: J2.8, U2.20 (IO12)
Col15: J2.10, U2.18 (IO10)
D+: J4.A6 (D+), J4.B6 (D+), U1.3 (I/O2)
D-: J4.A7 (D-), J4.B7 (D-), U1.1 (I/O1)
DP+: U1.4 (I/O2), U2.14 (USB_D+)
DP-: U1.6 (I/O1), U2.13 (USB_D-)
EN: C8.1, R10.2, RST1.2, U2.3 (EN)
GND: BOOT1.1, C1.2, C2.2, C3.2, C4.2, C5.1, C6.1, C7.2, C8.2, C9.2, C10.2, C11.1, J2.14, J2.18, J3.2, J4.A1 (GND), J4.A12 (GND), J4.B1 (GND), J4.B12 (GND), J4.SH (SHIELD), PS1.2 (GND), Q1.2 (S), R1.2, R2.2, R7.1, R13.2, RST1.1, Rprog1.2, Rprog3.2, Rtherm1.2, U1.2 (GND), U2.1 (GND), U2.40 (GND), U2.41 (GND), U3.3 (SEL), U3.9 (~TE), U3.10 (V_{SS}), U3.11 (V_{SS}), U3.21 (V_{SS})
L1: J2.16, U2.34 (IO41)
L2: J2.25, U2.5 (IO5)
L3: J2.23, U2.7 (IO7)
L4: J2.1, U2.31 (IO38)
L5: J2.12, U2.26 (IO45)
Mute_btn: J2.20, U2.9 (IO16)
unnamed: J4.A5 (CC1), R1.1
unnamed: J4.B5 (CC2), R2.1
unnamed: PG1.2 (A), R4.2
unnamed: Q1.3 (D), Q2.1 (G), R11.2
unnamed: Q2.3 (D), R12.1
unnamed: R5.2, STAT1.2 (A)
unnamed: STAT1.1 (K), U3.8 (STAT1/~LBO)
unnamed: R6.2, STAT2.2 (A)
unnamed: STAT2.1 (K), U3.7 (STAT2)
unnamed: Rprog1.1, U3.13 (PROG1)
unnamed: Rprog3.1, U3.12 (PROG3)
unnamed: Rtherm1.1, U3.5 (THERM)
unnamed: R3.2, R7.2, U3.2 (VPCC)
PG: PG1.1 (K), R8.2, U2.35 (IO42), U3.6 (~PG)
VBUS: C4.1, J4.A4 (VBUS), J4.A9 (VBUS), J4.B4 (VBUS), J4.B9 (VBUS), R3.1, R4.1, R5.1, R6.1, U1.5 (VBUS), U3.4 (PROG2), U3.18 (IN), U3.19 (IN)
VCC: C1.1, C9.1, PS1.1 (VIN), PS1.3 (STBY), U3.1 (OUT), U3.20 (OUT)
Vbat_Mes: J3.1, Q2.2 (S), R11.1, SW1.2 (B)
Vol_Down: J2.26, U2.4 (IO4)
Vol_Up: J2.24, U2.6 (IO6)

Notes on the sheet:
Chargeur de batterie intelligent
Mesure de la batterie
Boutons BOOT et RST
Connecteur Clavier
Batterie Li-ion 1s 3,7v
ESP32 S3
Connecteur USB-C Femelle et protection ESD
Régulateur 3v3

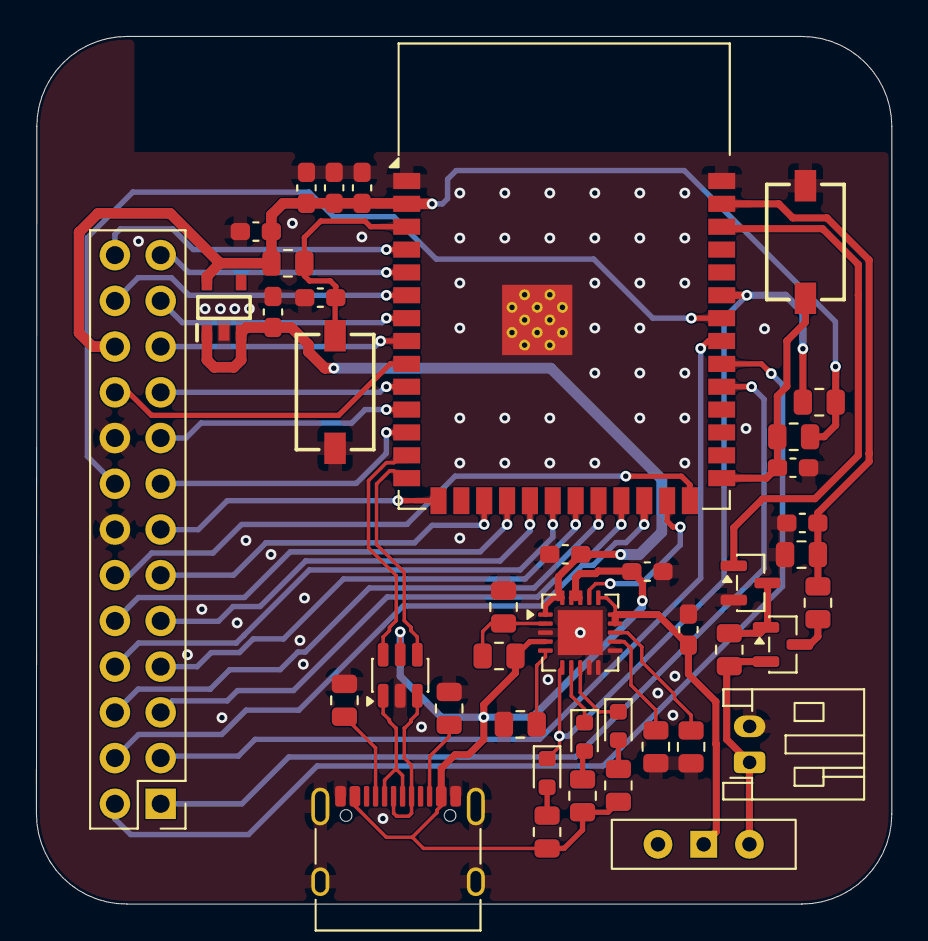
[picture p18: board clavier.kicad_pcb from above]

Board: 2 copper layers, 47.5 x 48.2 mm, 42 parts (0 on the bottom side), 52 nets.

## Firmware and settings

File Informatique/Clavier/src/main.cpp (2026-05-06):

#include <Arduino.h>
#include <Keypad.h>
#include "USB.h"
#include "USBHIDKeyboard.h"
#include "MyEncoder.h"
#include <esp_now.h>
#include <WiFi.h>
// --- Configuration Matrice (5x15) ---
const byte ROWS = 5;
const byte COLS = 15;
byte rowPins[ROWS] = {41, 5, 7, 38, 45};
byte colPins[COLS] = {15, 17, 18, 8, 3, 9, 11, 13, 21, 40, 39, 47, 14, 12, 10};

char keys[ROWS][COLS] = {
  {'\0','1','2','3','4','5','6','7','8','9','0','\0','=',KEY_BACKSPACE,KEY_DELETE},
  {KEY_TAB,'q','w','e','r','t','y','u','i','o','p','\0','\0','\0',KEY_RETURN},
  {KEY_CAPS_LOCK,'a','s','d','f','g','h','j','k','l',';','\0','\0',KEY_ESC},
  {KEY_LEFT_SHIFT,'<','z','x','c','v','b','n','m',',','.','/',KEY_PAGE_DOWN,KEY_UP_ARROW,KEY_PAGE_UP},
  {KEY_LEFT_CTRL,KEY_LEFT_GUI,KEY_LEFT_ALT,'\0',' ','\0',KEY_RIGHT_ALT,'\0','\0','\0','\0','\0',KEY_LEFT_ARROW,KEY_DOWN_ARROW,KEY_RIGHT_ARROW}, 
};        

// Gestion de ESP-NOW
uint8_t DongleMacAdress[] = {0xDC,0xB4,0xD9, 0x14,0x42,0x18};
esp_now_peer_info_t infosRecepteur;                             
// Objets
USBHIDKeyboard Keyboard;
USBHIDConsumerControl ConsumerControl;
Keypad keypad = Keypad(makeKeymap(keys), rowPins, colPins, ROWS, COLS);
MyEncoder encoder = MyEncoder(4,6,42);

void EncoderAction(int cmd) {
  ConsumerControl.press(cmd);
  delay(10);
  ConsumerControl.release();
}

void sendData(uint16_t data){
  esp_now_send(DongleMacAdress, (uint8_t *) &data, sizeof(data));
}

void setup() {
  Serial.begin(115200);  
  WiFi.mode(WIFI_STA);
  if (esp_now_init() != ESP_OK) {
    Serial.println("Erreur d'initialisation ESP-NOW");
    return;
  }
  Serial.println("ESP-NOW Ok");
  memcpy(infosRecepteur.peer_addr, DongleMacAdress, 6);
  infosRecepteur.channel = 0;  
  infosRecepteur.encrypt = false;
  if (esp_now_add_peer(&infosRecepteur) != ESP_OK){
    Serial.println("Échec de l'appairage");
    return;
  }
  USB.begin();
  encoder.init();
  encoder.onIncrement(EncoderAction, CONSUMER_CONTROL_VOLUME_INCREMENT);
  encoder.onDecrement(EncoderAction, CONSUMER_CONTROL_VOLUME_DECREMENT);
  encoder.onPress(EncoderAction, CONSUMER_CONTROL_MUTE);
  Keyboard.begin();
  delay(2000);
}

void loop() {
  encoder.loop();
  if (keypad.getKeys()) {
    for (int i=0; i<LIST_MAX; i++) {
      if (keypad.key[i].kchar != '\0' && keypad.key[i].stateChanged) {        
        uint8_t keyToSend = (uint8_t)keypad.key[i].kchar;
        switch(keypad.key[i].kstate){
          case PRESSED:
            Serial.print("Appui: ");
            Serial.println(keypad.key[i].kchar);
            // On envoie le code normal (bit 15 à 0)
            // sendData(keypad.key[i].kchar);
            Keyboard.press(keypad.key[i].kchar);
            Keyboard.release(keypad.key[i].kchar);
            break;
          case RELEASED:
            // CRUCIAL : On prévient le récepteur du relâchement pour SHIFT et GUI (Windows)
            // if(keypad.key[i].kchar == KEY_LEFT_SHIFT || keypad.key[i].kchar == KEY_LEFT_GUI) {
            //   Serial.print("Relâchement spécial: ");
            //   Serial.println(keypad.key[i].kchar);
            //   // On envoie le code avec le flag de relâchement (bit 15 à 1)
            //   sendData(keypad.key[i].kchar | 0x8000);
            // }
            break;
            
          case HOLD: 
            break;
        }
      }
    }
  }
}

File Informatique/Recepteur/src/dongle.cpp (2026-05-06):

#include <Arduino.h>
#include <WiFi.h>
#include <esp_now.h>
#include <USB.h>
#include <USBHIDKeyboard.h>
#include <USBHIDConsumerControl.h> // Ajouter ceci
USBHIDKeyboard Keyboard;
USBHIDConsumerControl ConsumerControl;

unsigned long winPressTime = 0;
bool winActive = false;
bool comboUsed = false;

void OnDataRecv(const uint8_t * mac, const uint8_t *incomingDataRaw, int len) {
  uint16_t received;
  memcpy(&received, incomingDataRaw, sizeof(received));

  bool isReleased = (received & 0x8000);
  uint16_t keyCode = (received & 0x7FFF);

  // --- CAS DE LA TOUCHE WINDOWS ---
  if (keyCode == KEY_LEFT_GUI) {
    if (!isReleased) {
      winActive = true;
      comboUsed = false;
      winPressTime = millis();
      Keyboard.press(KEY_LEFT_GUI); // On prépare le modificateur
      Serial.println("Win pressé (en attente...)");
    } 
    else {
      winActive = false;
      Keyboard.release(KEY_LEFT_GUI); // On relâche le modificateur
      
      // Si on relâche Win sans avoir utilisé de raccourci (ex: Win+R)
      // et que l'appui était court (optionnel, ici on simplifie)
      if (!comboUsed) {
        Serial.println("Simple Tap détecté -> Envoi Ctrl+Esc");
        Keyboard.press(KEY_LEFT_CTRL);
        Keyboard.press(KEY_ESC);
        delay(50);
        Keyboard.releaseAll();
      }
    }
    return;
  }

  // --- CAS DES AUTRES TOUCHES ---
  if (isReleased) {
    Keyboard.release(keyCode);
  } 
  else {
    if (winActive) {
      comboUsed = true; // On marque qu'un raccourci est en cours (ex: Win + R)
      Serial.println("Combinaison Windows + Touche détectée");
    }
    Keyboard.press(keyCode);
    
    // Si ce n'est pas une touche de modification (comme Shift), 
    // on peut relâcher immédiatement pour simuler une frappe
    if (keyCode != KEY_LEFT_SHIFT && keyCode != KEY_LEFT_CTRL && keyCode != KEY_LEFT_ALT) {
       delay(20);
       Keyboard.release(keyCode);
    }
  }
}
void setup() {
  Serial.begin(115200);
  Keyboard.begin();
  ConsumerControl.begin();
  USB.begin();
  WiFi.mode(WIFI_STA);
  Serial.println(WiFi.macAddress());
  if (esp_now_init() != ESP_OK) return;
  esp_now_register_recv_cb(esp_now_recv_cb_t(OnDataRecv));
  delay(2000);
  ConsumerControl.press(CONSUMER_CONTROL_VOLUME_INCREMENT);
  ConsumerControl.release();
} 
void loop() {
}

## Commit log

2025-12-24 création du fichier kicad
    [pcb.kicad_pcb, pcb.kicad_sch]
2026-01-12 Enhance README with project details and specifications
    Updated project description to include details about the keyboard's power system, microcontroller specifications, and communication protocol.
2026-01-15 Add ESP32 C3 and S3 datasheet links to README
    Added links to ESP32 C3 and S3 datasheets.
2026-01-15 Add ESP32 S3 datasheet link to README
2026-01-15 Add USB C support to ESP32-S3 specifications
    Added USB C support for wired mode in hardware specifications.
2026-01-15 update schema
    [Dongle.kicad_sch, Emetteur.kicad_sch, PCB.kicad_pcb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]
2026-01-16 Update images for ESP32-S3-MINI in README
    Updated images in the README for the ESP32-S3-MINI section.
2026-01-16 update schema & pcb
    [PCB-B_Cu.gbl, PCB-B_Mask.gbs, PCB-B_Paste.gbp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]
2026-01-16 Réorganisation de la structure du projet
    [Dongle.kicad_sch, Emetteur.kicad_sch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]
2026-01-16 Ajout de début de code pour les 2 produits
2026-01-18 Revise project structure in README
    Updated project structure to include new directories for KiCad libraries and clarified existing sections.
2026-01-18 edit schema
    [PCB.kicad_sch, pcb.kicad_pcb, pcb.kicad_sch]
2026-01-18 Update Readme with electronic keyboard details
    Added sections on power management and battery handling.
2026-01-18 Add image for power regulation in keyboard README
    Added an image to illustrate the power regulation and switching mechanism for the keyboard.
2026-01-18 Add image for keyboard power regulation section
    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
2026-01-18 Enhance Readme with LDO and voltage regulation details
    Added details about LDO selection and voltage regulation for the keyboard.
2026-01-25 Enhance README with new component details
    Updated the README to include additional details about visual indicators and the addition of transistors Q3 and Q4 for battery voltage measurement.
2026-01-25 update keyboard schematic
    [PCB.kicad_pcb, PCB.kicad_sch, batterie.kicad_sch]
2026-03-22 Update voltage regulation description in README
    Clarified voltage regulation details for power sources.
2026-03-29 global update
    [clavier.kicad_pcb, puceNRF.kicad_pcb, puceNRF.kicad_sch]
2026-03-29 remove of clavier_test
    [test-B_Cu.gbr, test-B_Mask.gbr, test-B_Paste.gbr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]
2026-04-02 Revise README for keyboard electronics and matrix design
    Updated the README to reflect changes in the electronic keyboard design, including the matrix layout, ghosting issue, and encoder management.
2026-04-03 Add communication protocols section to README
    Added sections on wireless and PC communication protocols using ESP-NOW and USB libraries.
